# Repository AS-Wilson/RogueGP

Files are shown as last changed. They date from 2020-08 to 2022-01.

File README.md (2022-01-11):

# RogueGP
Rouge Racing Team GreenPower Repository, for all design documents (Mechanical, Electronic, and Software)

# Renders

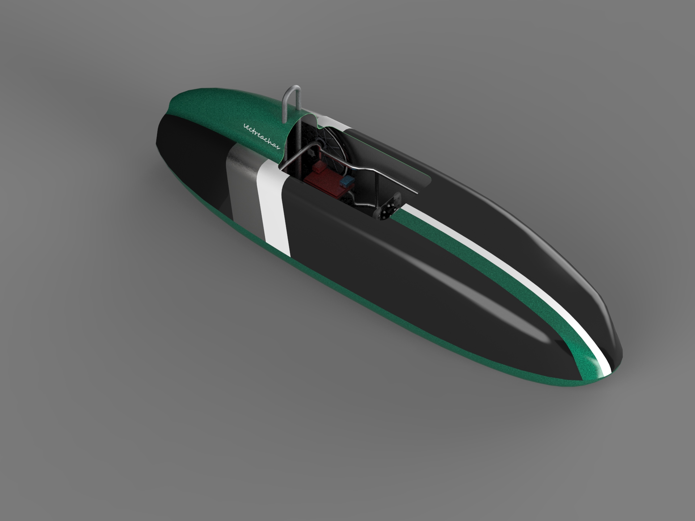
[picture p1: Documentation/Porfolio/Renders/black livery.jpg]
Black Livery


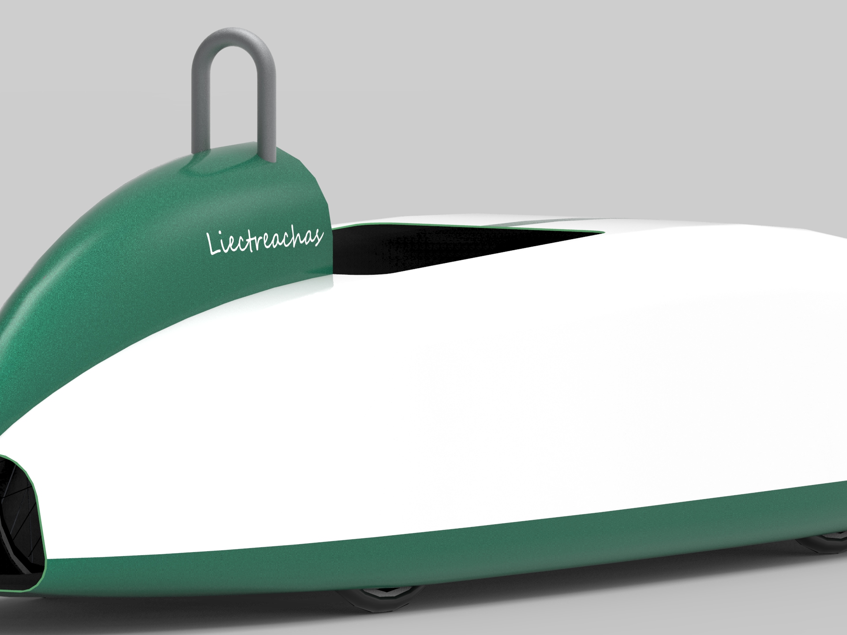
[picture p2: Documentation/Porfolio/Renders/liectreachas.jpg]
Liectreachas


# Current Build Progress and Some Race Photos

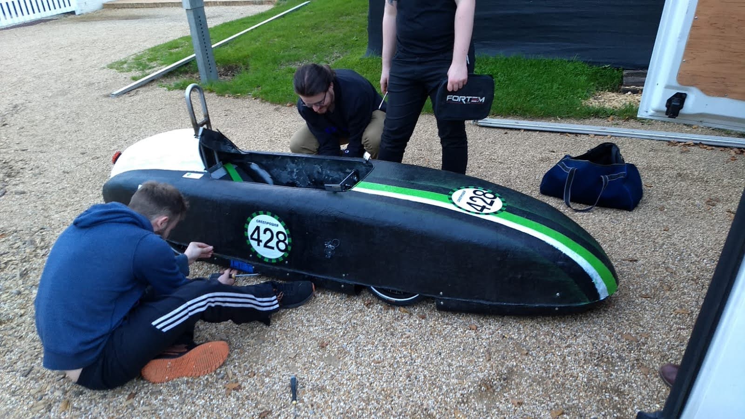
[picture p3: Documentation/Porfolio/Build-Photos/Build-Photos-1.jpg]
Build Photo One


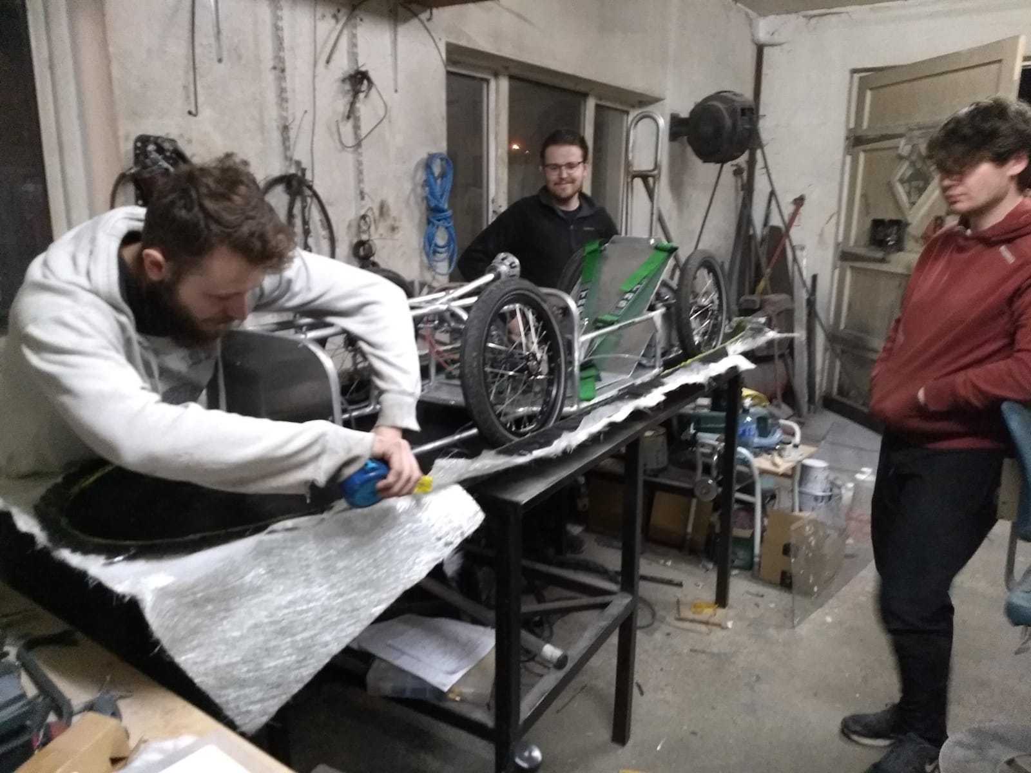
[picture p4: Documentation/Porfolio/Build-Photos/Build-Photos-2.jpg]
Build Photo Two


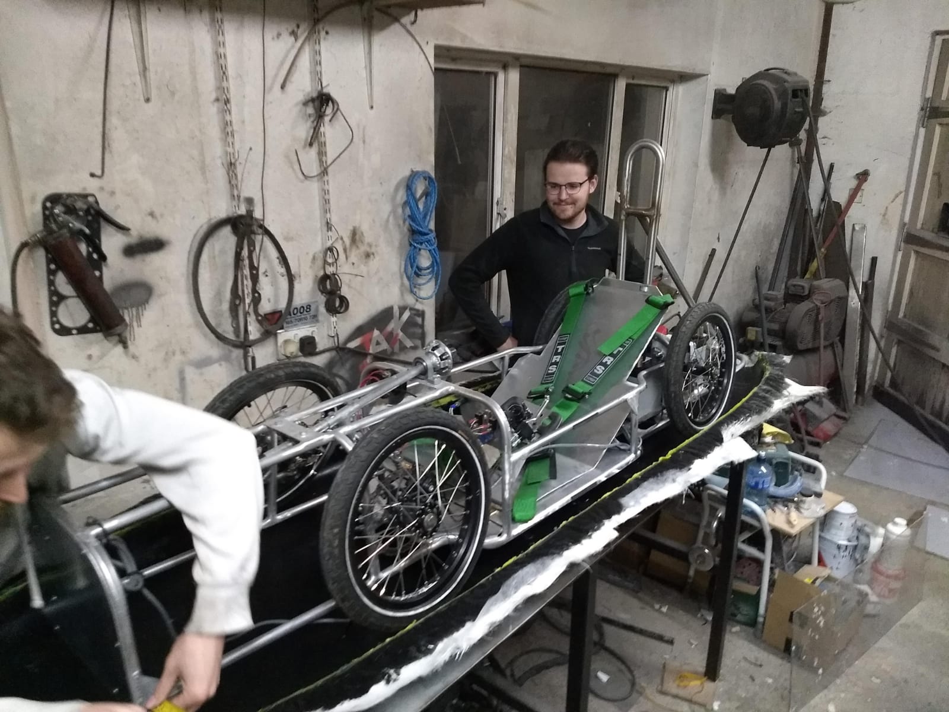
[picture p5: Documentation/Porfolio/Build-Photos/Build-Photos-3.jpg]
Build Photo Three


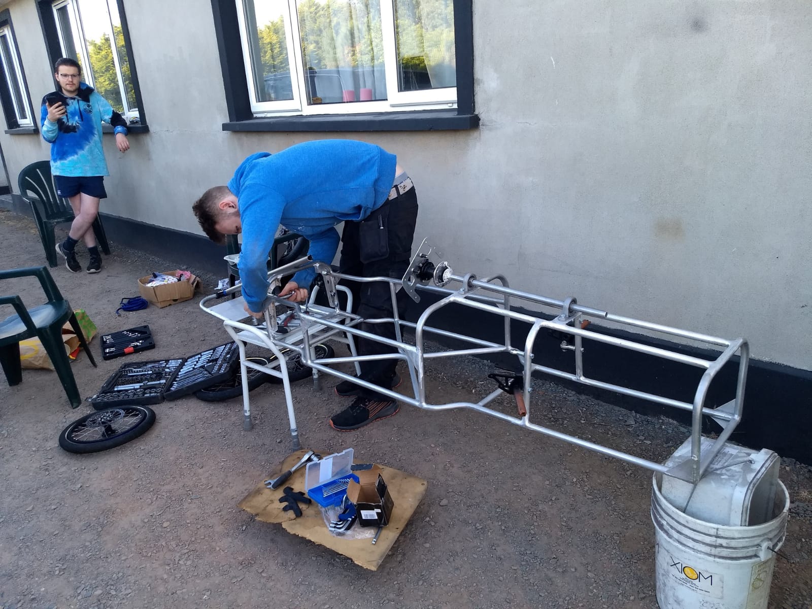
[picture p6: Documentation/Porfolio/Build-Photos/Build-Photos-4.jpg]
Build Photo Four


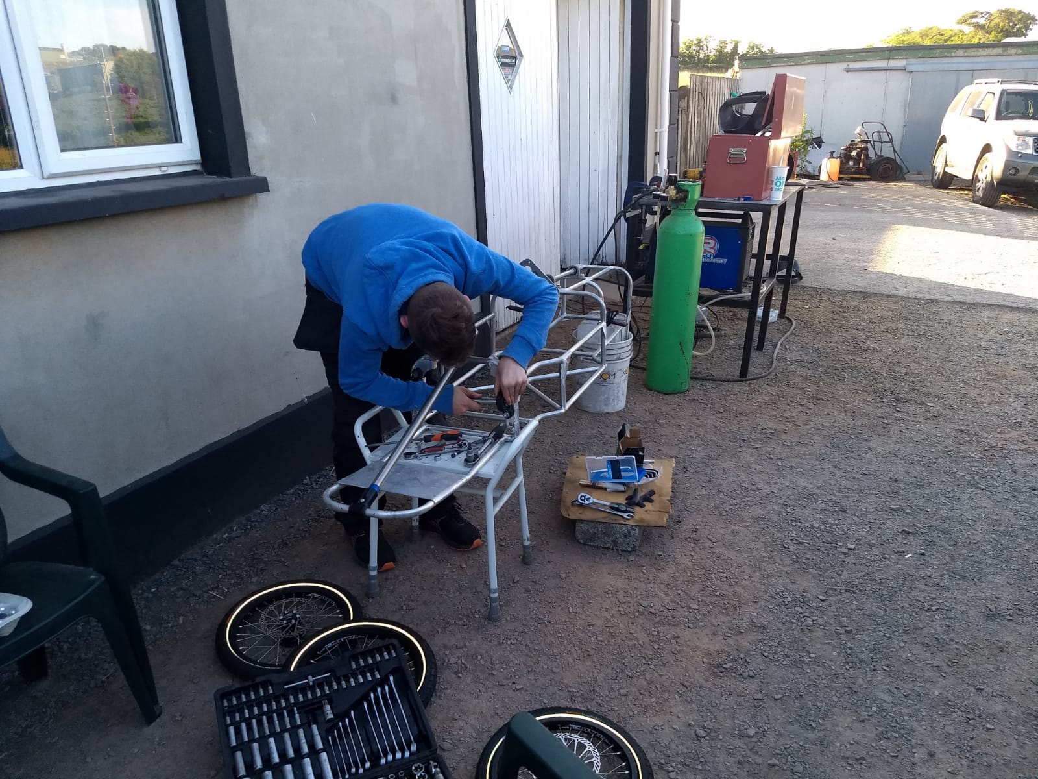
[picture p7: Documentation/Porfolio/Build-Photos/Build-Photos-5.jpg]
Build Photo Five


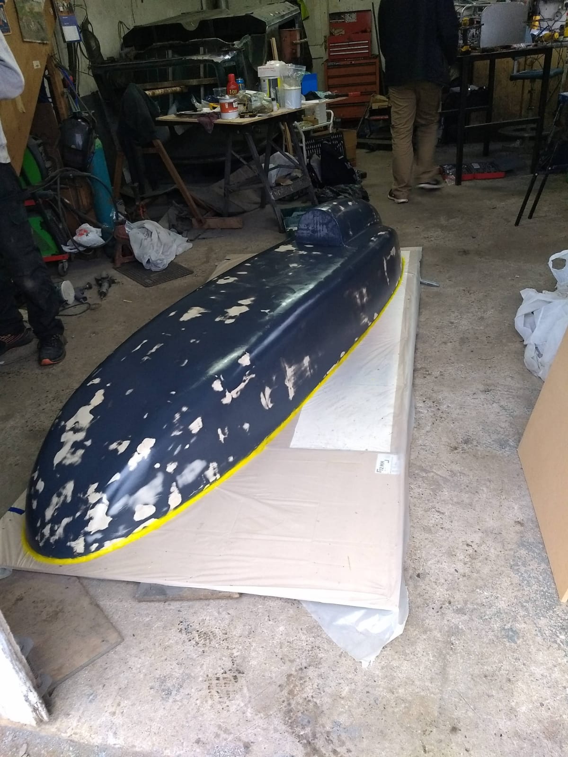
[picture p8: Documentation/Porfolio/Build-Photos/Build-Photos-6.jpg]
Build Photo Six


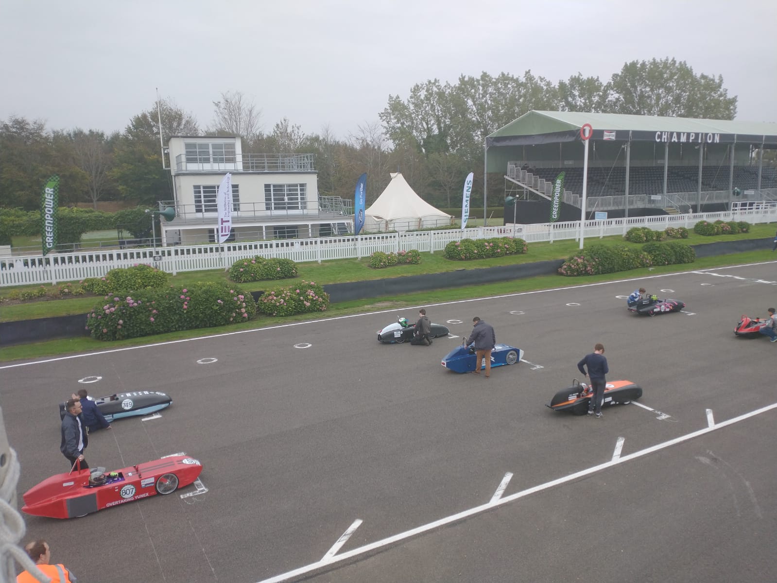
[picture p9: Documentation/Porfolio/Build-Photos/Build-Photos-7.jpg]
Build Photo Seven


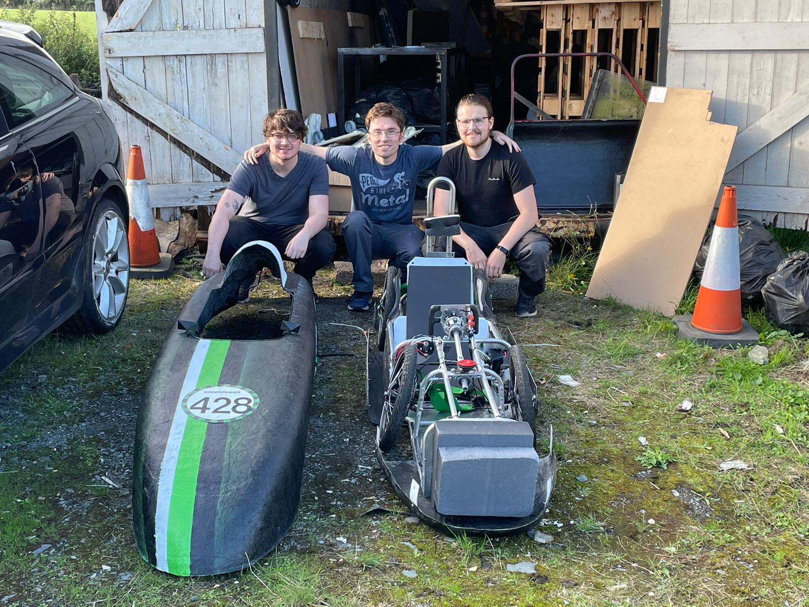
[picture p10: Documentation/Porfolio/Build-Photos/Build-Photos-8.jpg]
Build Photo Eight


Build Photo Nine

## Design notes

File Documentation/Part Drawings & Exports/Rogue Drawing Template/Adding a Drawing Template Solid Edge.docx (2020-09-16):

Adding a Drawing Template Solid Edge

Make a copy of the RR Drawing Template off Github.

Go to:

Program Files > Siemens > Solid Edge 2020 > Template > ISO Metric

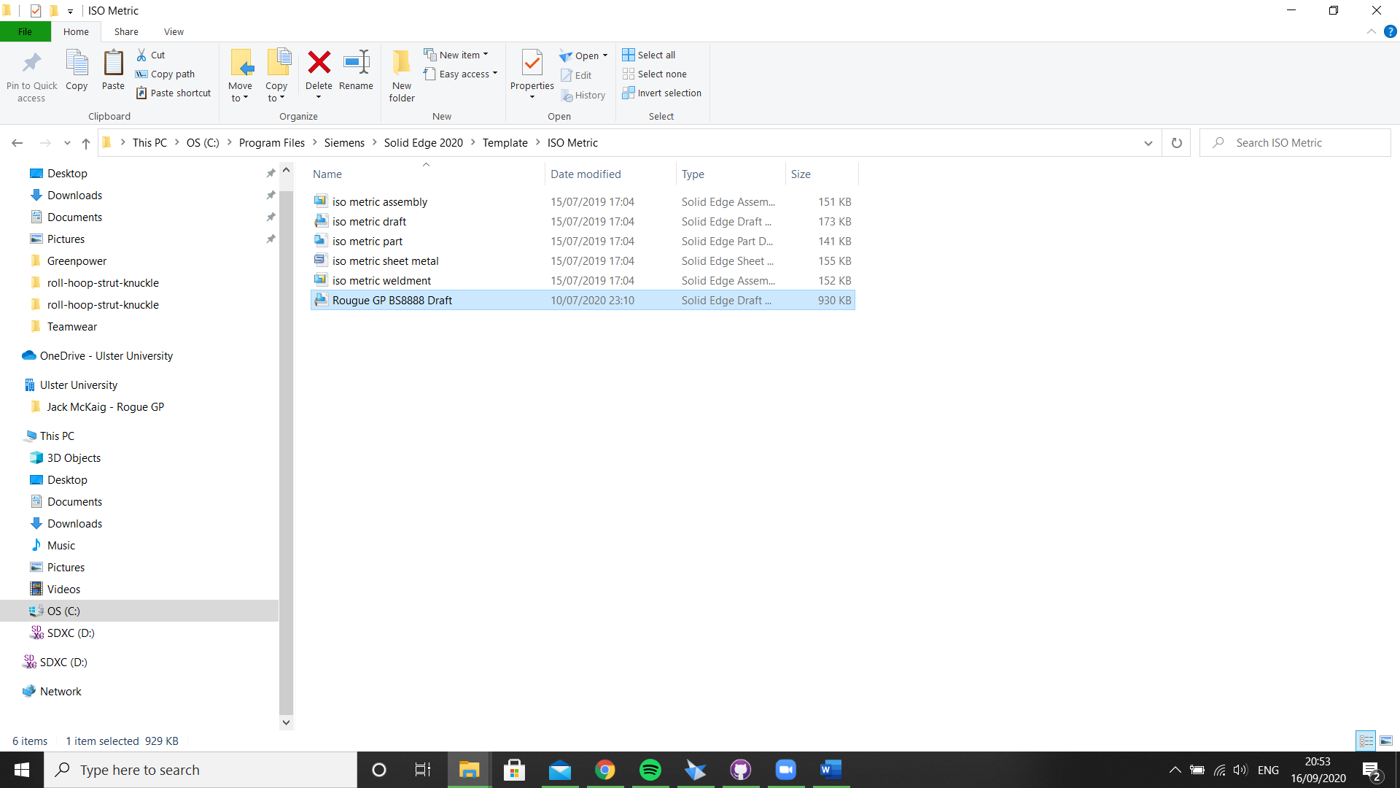
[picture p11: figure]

Paste Drawing template into this file and check Solid Edge to see if it has been added successfully.

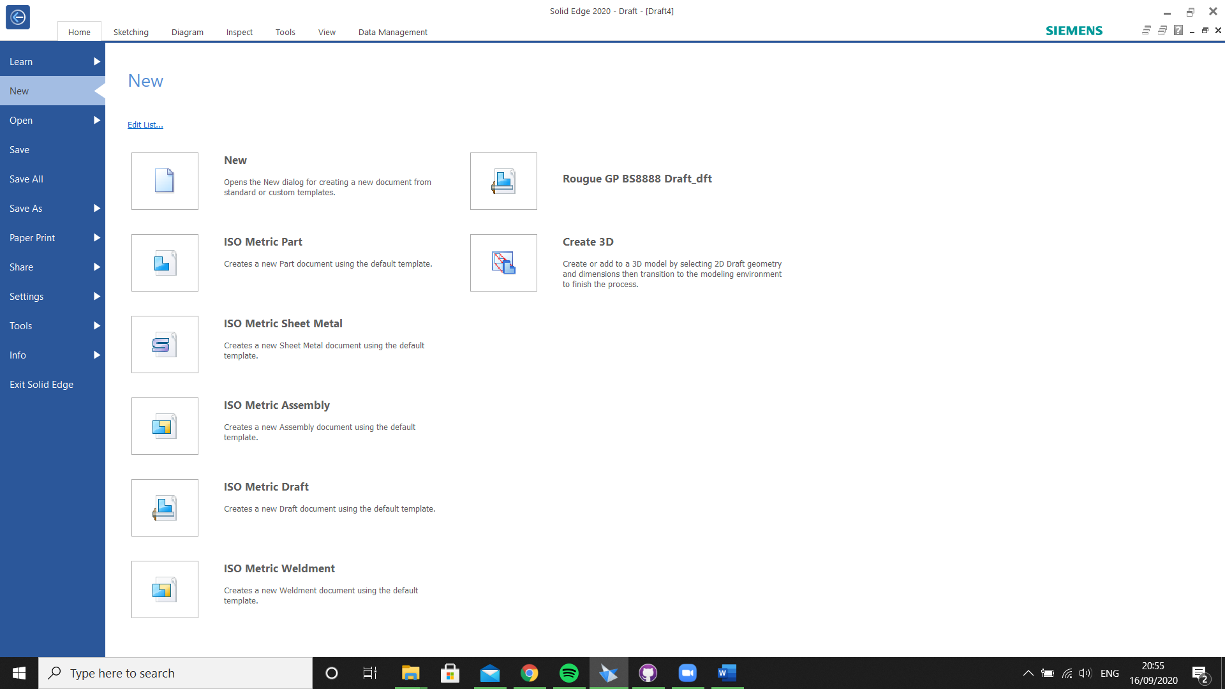
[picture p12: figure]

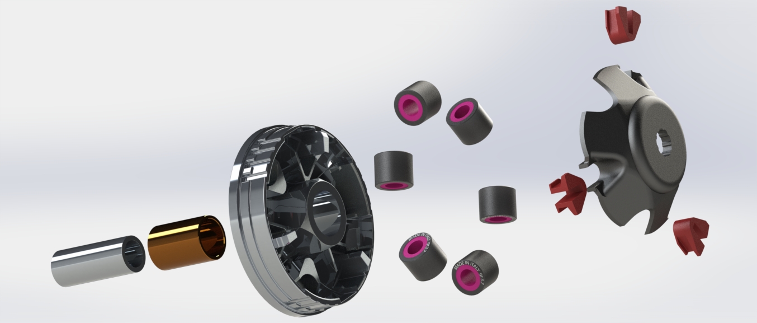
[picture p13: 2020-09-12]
Mechanical/drivetrain/CVT/example-CVT/Variator-multivar2000/rendering-exploded view.JPG

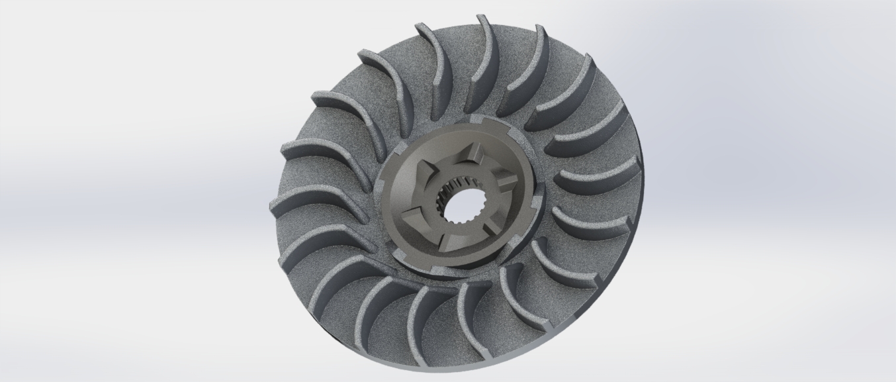
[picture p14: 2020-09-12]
Mechanical/drivetrain/CVT/example-CVT/ventilvar/rendering.JPG

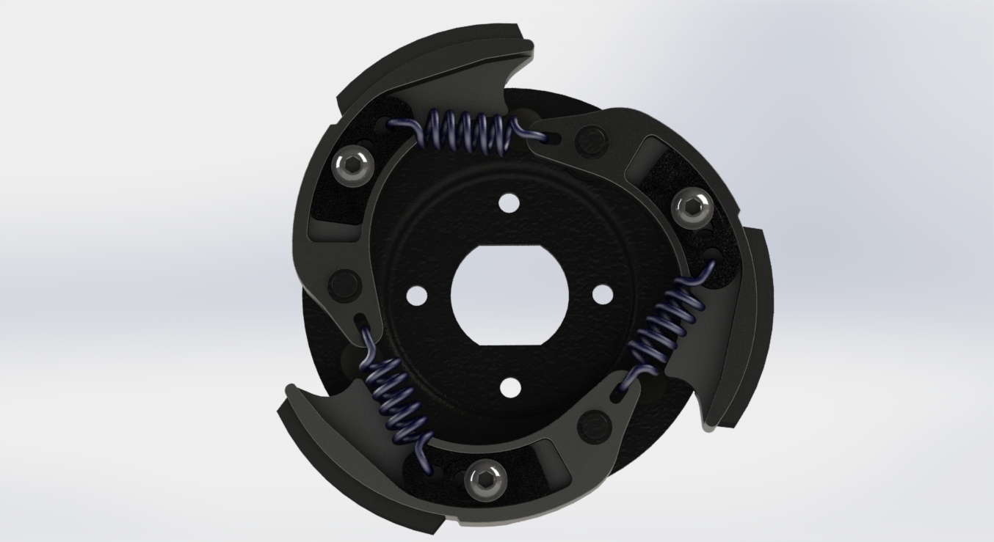
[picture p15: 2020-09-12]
Mechanical/drivetrain/CVT/example-CVT/Clutch/render4.JPG

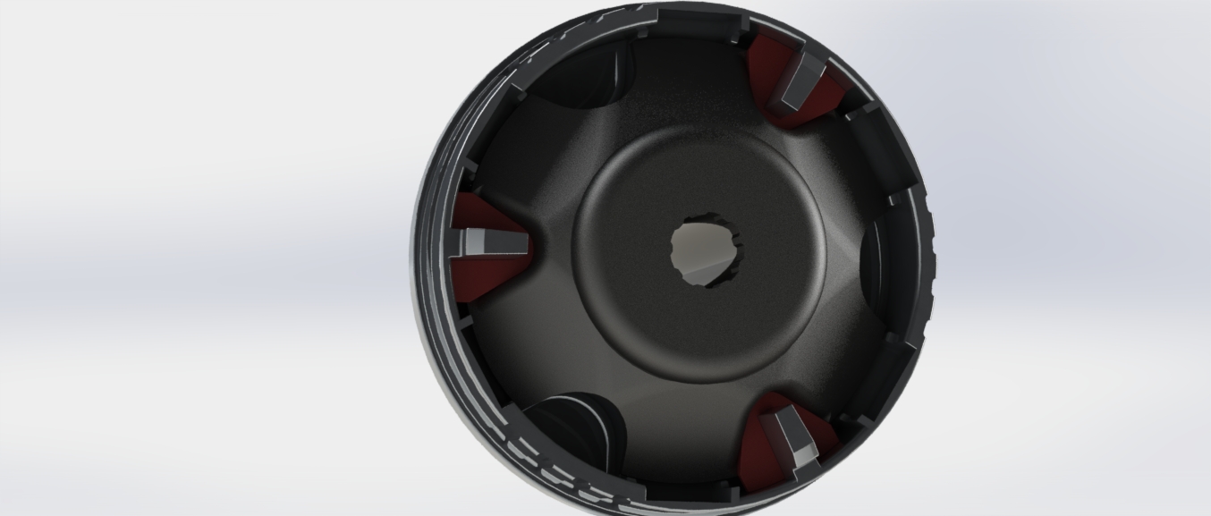
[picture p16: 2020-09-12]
Mechanical/drivetrain/CVT/example-CVT/Variator-multivar2000/preview.JPG

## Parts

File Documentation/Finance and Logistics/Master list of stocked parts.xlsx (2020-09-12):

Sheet: Steering
 | Steering system components |  |  | Procurment
Item No. | Component/materials list | Required Quantity | Stocked Quantity | Quote 1 | Quote 2 | Ordered?
1 | Threaded bar m8 2 metre | 1 | 5 | N/A | N/A | N/A
2 | Upright | 5 | 2 | £176 for pair (https://www.greenpower.co.uk/product/308) | N/A | Y
3 | steering column | 1 | 3 | £22.65 each (https://www.kkckartshop.co.uk/steering-column-m8-x-550mm.html) | £23 each (https://www.zipnorth.com/product/steering-column-m8/) | Y
4 | steering pillow bearings |  |  | £7.70 each (https://simplybearings.co.uk/shop/p22932/SBPP204-Pressed-Steel-Pillow-Block-Housing-with-20mm-Insert/product_info.html) | £10 each (http://www.bearingshopuk.co.uk/lpb20-pressed-steel-pillow-block/)
5 |  |  |  |  |  | made in house
6
7
8
9
10
11
12
13
14
15
16
17
18
19
20

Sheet: Power Unit
 | Power Unit components |  |  | Procurment
Item No. | Component/materials list | Quantity | Stocked? | Quote 1 | Quote 2 | Ordered?
1 | Spare Motor | 1 |  | £161.03 each (https://www.greenpower.co.uk/product/163) | N/A | Y
2 | Scooter for CVT and brakes | 2
3 | Thick aluminium bar for heatsink | 1
4 | Thermal paste | TBC
5 | Cooling fan | 2
6 | Motor | 1
7
8
9
10
11
12
13
14
15
16
17
18
19

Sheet: Wheels and Brakes
 | Wheels and brakes components |  |  | Procurment
Item No. | Component/materials list | Quantity | Stocked? | Quote 1 | Quote 2 | Ordered?
1 | 16" wheel rims | 4
2 | 16" rim tape | 4
3 | 16" tyres | 4
4 | 16" tyre tubes | 6
5 | Brake cable | 2
6 | brake lever | 2
7 | Cable caps |  |  | £1 for 10 (https://www.halfords.com/cycling/bike-parts/bike-brakes/halfords-gear-brake-cable-end-covers) | £1.49 for 10 (https://www.chainreactioncycles.com/lifeline-cable-ends/rp-prod155573?sku=sku568333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)
8 | Drum brake set | 1
9
10
11
12
13
14
15
16
17
18
19
20

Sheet: Chassis and Bodywork
 | Chassis frame components |  |  | Procurment
Item No. | Component/materials list | Quantity | Stocked? | Quote 1 | Quote 2 | Ordered?
1 | steel roll bar 3m 25mm 1.5mm | 1 |  | /
2 | rear axle bar 1m 3/4" | 1 |  | /
3 | box of pop rivets | 2
4 | bonnet pins | 8 |  | £17.99 for 2 (https://www.amazon.co.uk/CICMOD-Universal-Racing-Bonnet-without/dp/B07P1733YV?s=automotive) | 2 for £43.40 (https://www.aerocatch.com/product/120-2000-above-panel/)
5 | 20mm aluminium tubing 1.5mm | 20m |  | /
6 | Plywood Sheets 9mm | 3 |  | JP Corry qoute | £18.46 each (https://eglantinetimber.com/product/plywood/) | Y
7
8 | Flat bar 4m 20x3mm | 1 |  | /
9 | Flat bar 4m 20x2mm | 1 |  | /
10
11 | Blue foam sheet | 6 |  | £28.35 each minimum qty = 6 (https://www.panelsystems.co.uk/product/styrofoam) | £51.40 each (http://modelshop.co.uk/Shop/Item/Styrofoam-100mm-large-sheet/ITM7246) | Y
12
13
14
15
16
17
18
19
20

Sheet: Safety Equipment
 | Safty Equipment |  |  | Procurment
Item No. | Component/materials list | Quantity | Stocked? | Quote 1 | Quote 2 | Ordered?
1 | New Helmets | 2
2 | 5 point harness | 1 |  | £178.00 each (https://www.greenpower.co.uk/product/71) | £74.98 each (https://www.demon-tweeks.com/uk/race-safety-accessories-lightweight-nascar-5-point-harness-546549/)
3 | mirrors | 2
4
5
6
7
8
9
10
11
12
13
14
15
16
17
18
19
20

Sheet: Fasteners
 | Fasters |  |  | Procurment
Item No. | Component/materials list | Quantity | Stocked? | Quote 1 | Quote 2 | Ordered?
1
2
3
4
5
6
7
8
9
10
11
12
13
14
15
16
17
18
19
20

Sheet: Livery
 | Livery materials |  |  | Procurment
Item No. | Component/materials list | Quantity | Stocked? | Quote 1 | Quote 2 | Ordered?
1 | Vinyl sheet (purple)
2 | Vinyl USSE logo
3 | Vinyl Ulster University logo
4 | Vinyl Santaner logo (red)
5
6
7
8
9
10
11
12
13
14
15
16
17
18
19
20

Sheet: Wiring and Electronics
 | Wiring components |  |  | Procurment
Item No. | Component/materials list | Quantity | Stocked? | Quote 1 | Quote 2 | Ordered?
1 | New Batteries | 2 |  | £60.74 each (https://www.greenpower.co.uk/product/177) | N/A | Y
2 | 10m of 10mm red wire | 1 |  | £26.70 for 10m (https://uk.farnell.com/pro-power/pp001276/tri-rated-wire-10mm2-red-1m/dp/2528181?st=10mm%20red%20wire) | N/A | \
3 | 10m of 10mm black wire | 1 |  | £26.70 for 10m (https://uk.farnell.com/pro-power/pp001192/tri-rated-wire-10mm2-black-1m/dp/2528088) | N/A | \
4 | Reel of thin black wire | 1 |  | \ | \ | \
5 | Reel of thin red wire | 1 |  | £22.88 for 100m (https://uk.farnell.com/pro-power/pp001272/tri-rated-wire-1-5mm2-red-100m/dp/2501520?st=1.5mm%20red%20wire) | N/A | \
6 | box of Crimp terminals | 2 |  | \ | \ | \
7 | Brake light | 1 |  | £9.95 for 4 (https://www.amazon.co.uk/Justech-Position-Universal-Trailer-Caravan/dp/B078J17YDH) | 11.30 for 1 (https://www.trailertek.com/trailer-parts/lighting/led-lights/led-autolamps-81rmb-square-stop-tail-lamp-12v-24v) | \
8 | microswitch | 2 |  | £11.83 for 5 (https://uk.rs-online.com/web/p/microswitches/1594449/) | N/A | \
9 | Accelerator switch (Red Button) | 2 |  | £3.71 each (https://uk.farnell.com/multicomp/mcpas6b2m1ce3/switch-spst-0-4a-32vac-ip67-red/dp/1638334) | N/A | \
10 | horn | 1 |  | £10.82 each (https://www.arc-components.com/0-642-16-12v-420hz-high-tone-2-pole-electric-horn-2373.html) | £14.55 each (https://www.greenpower.co.uk/product/39) | \
11 | horn switch (Blue Button) | 2 |  | £2.74 each (https://uk.farnell.com/multicomp/mcpas6b2m1ce7/switch-push-button-spst-ip67-blue/dp/1638332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) | N/A | \
12 | relay | 2 |  | £7.67 each (https://uk.farnell.com/te-connectivity/v23134j53d642/relay-automotive-spst-no-24vdc/dp/9913777) | N/A | \
13 | fuse | 10 |  | £7.83 for 10 (https://uk.rs-online.com/web/p/car-fuses/2193592/) | N/A | \
14 | Isolator Key and switcth | 1 |  | \ | \ | \
15 | bag of short cable ties | 1 |  | \ | \ | \
16 | bag of long cable ties | 1 |  | \ | \ | \
17 | bag of self ahesive pads | 1 |  | \ | \ | \
18 | New battery connectors | 2 |  | £14.85 for 2 (https://www.greenpower.co.uk/product/168) | £7.39 for 2 (https://www.amazon.co.uk/Qiorange-Release-Terminals-Motorhome-Terminal/dp/B075JCNMDC) | Y
19 | spare battery terminals | 4 |  | £9.60 for 2 (https://www.greenpower.co.uk/product/297) | N/A | Y
20 | fuse holder | 1 |  | £9.02 each (https://uk.rs-online.com/web/p/inline-fuse-holders/2506285/) | N/A | \
21
22
23 |  | 4
24 |  | 4
25 |  | 4
26 |  | 4

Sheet: Race Weekend items
 | Race weekend items |  |  | Procurment
Item No. | Component/materials list | Quantity | Stocked? | Quote 1 | Quote 2 | Ordered?
1
2 | New Overalls with gloves | 4 to 6
3 | Team shirts | 6 |  |  |  | Y
4 | car stand | 1
5 | GoPro | 1
6 | Roll of masking tape | 2
7 | pit board | 2
8 | umbrella for wet race start | 2
9 | Gazebo | 1
10 | Roll of Duct Tape | 2
11 | Foot/plug in pump | 1
12 | Battery insulation boxes | 2
13
14
15
16
17
18
19
20

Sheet: Communication
 | Communication items |  |  | Procurment
Item No. | Component/materials list | Quantity | Stocked? | Quote 1 | Quote 2 | Ordered?
1 | Team radios | 4
2 | closed face helmet mic | 2
3 | Telemetry system | 1 |  | \ | \ | outsourced
4
5
6
7
8
9
10
11
12
13
14
15
16
17
18
19
20

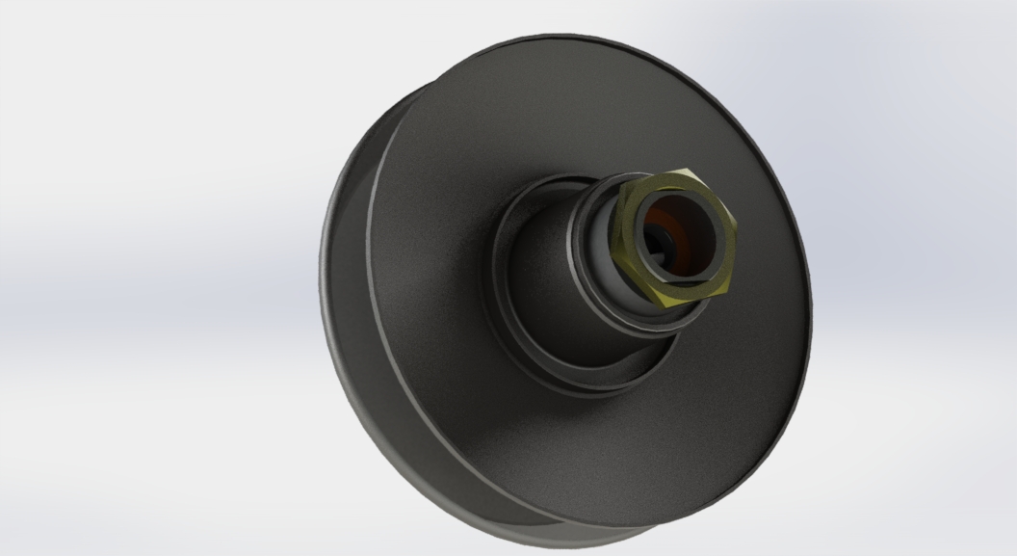
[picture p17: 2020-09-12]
Mechanical/standard-parts-&-example-designs/example-CVT/Torque-Driver/preview.JPG

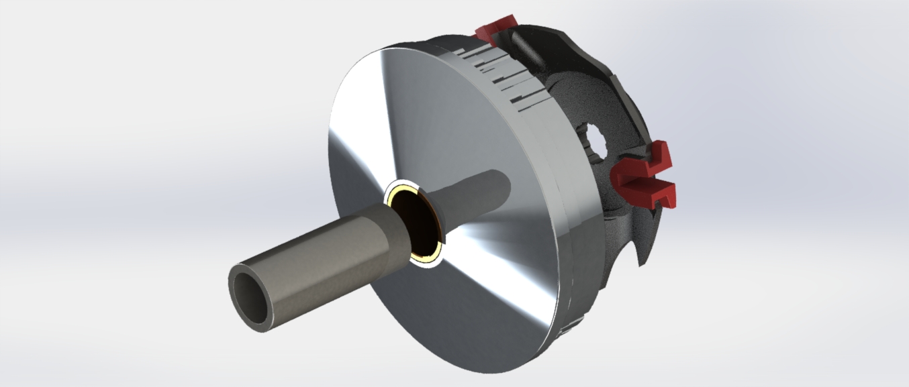
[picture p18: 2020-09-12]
Mechanical/standard-parts-&-example-designs/example-CVT/Variator-multivar2000/preview2.JPG

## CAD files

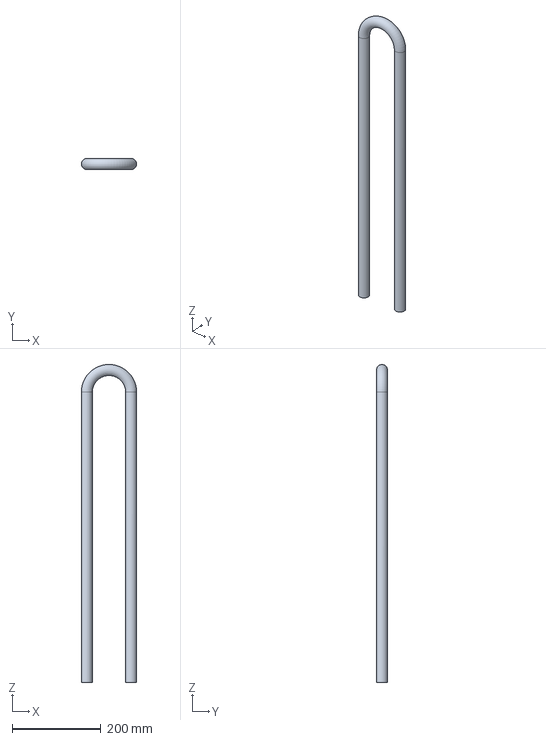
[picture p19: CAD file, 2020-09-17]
Mechanical/MB1000-chassis/roll-hoop/R720x100-roll-hoop/Exports/R720x100-roll-hoop-for-assembly.stp
125.0 x 25.0 x 717.4 mm

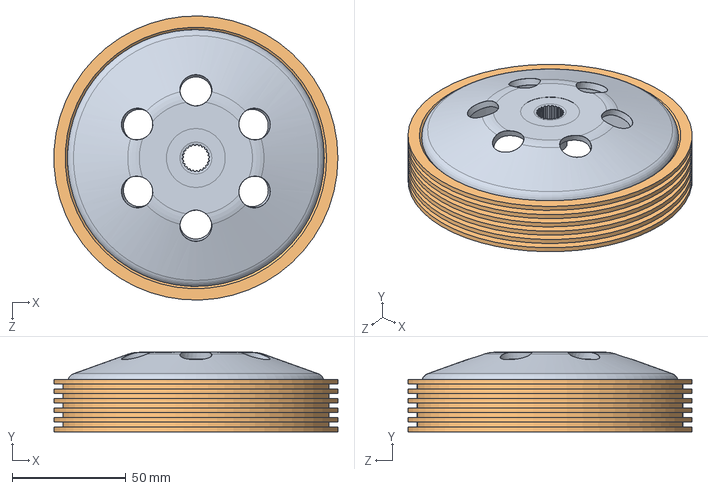
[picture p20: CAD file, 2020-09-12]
Mechanical/standard-parts-&-example-designs/example-CVT/Clutch-Bell/CLBAssembly.SLDASM
124.9 x 35.0 x 124.9 mm
CLBPart1
CLBPart2

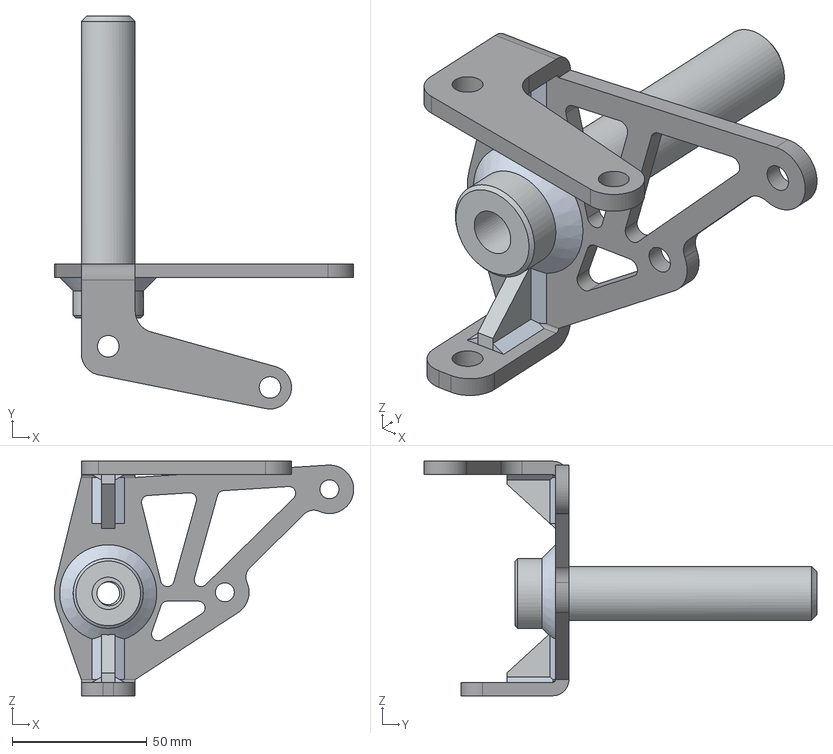
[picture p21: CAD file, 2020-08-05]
Mechanical/Suspension-&-Steering/Uprights/RH-Upright/Exports/RH-Upright-Assembly.stp
111.0 x 145.8 x 87.0 mm
RH-upright
RH-Upright-Assembly_469_690_Fillet 7_oa_0
RH-Upright-Assembly_469_690_Fillet 7_oa_1
front-axle
RH-Upright-Assembly_469_690_Fillet 7_oa_2
RH-Upright-Assembly_469_690_Fillet 7_oa_3
upright-gusset x 2
RH-Upright-Assembly_469_690_Fillet 7_oa_4
RH-Upright-Assembly_469_690_Fillet 7_oa_5
RH-Upright-Assembly_469_690_Fillet 7_oa_6

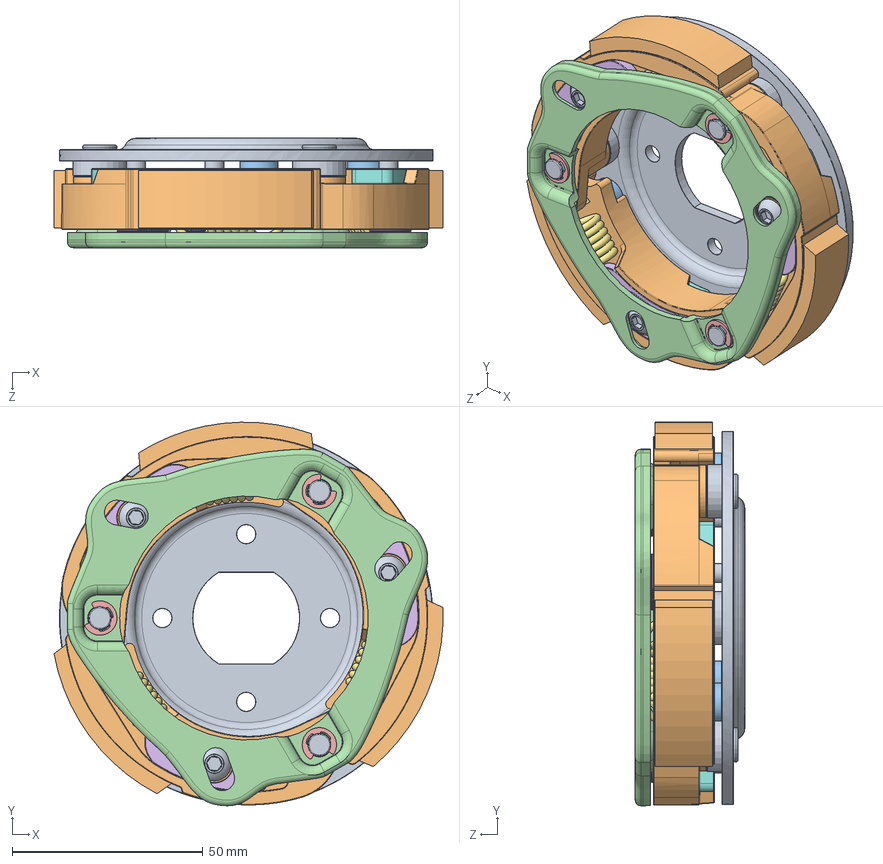
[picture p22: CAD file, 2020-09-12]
Mechanical/drivetrain/CVT/example-CVT/Clutch/CLAssembly.SLDASM
102.1 x 100.7 x 28.8 mm
frix1
coupling jaws x 3
CLpart7 x 3
CLPart3
seeger x 3
CLPart5 x 3
spring x 3
CLPart6 x 3
CLPart2 x 3
CLpart8 x 3

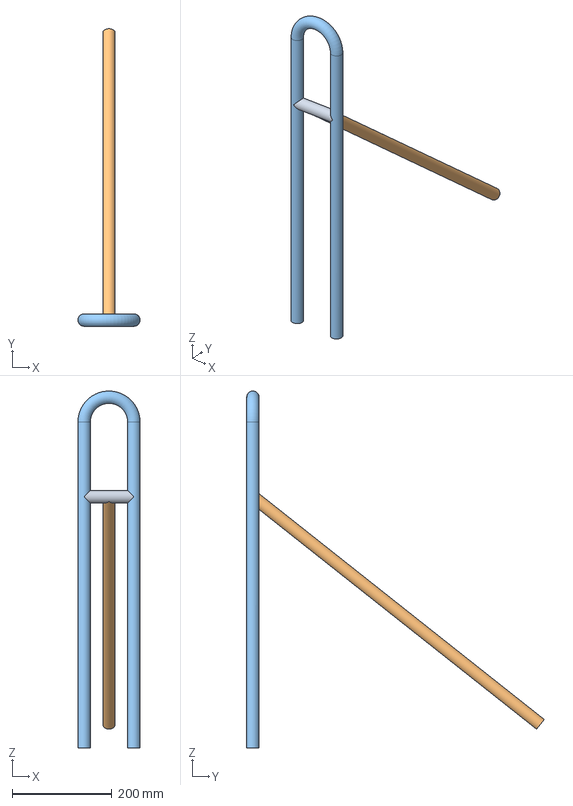
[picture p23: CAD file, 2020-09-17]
Mechanical/MB1000-chassis/roll-hoop/R720x100-roll-hoop/Exports/R720x100-roll-hoop-assembly.stp
125.0 x 598.1 x 717.5 mm
R720x100-roll-hoop-cross-member
R720-roll-hoop-bracing-strut
R720x100-roll-hoop-for-assembly

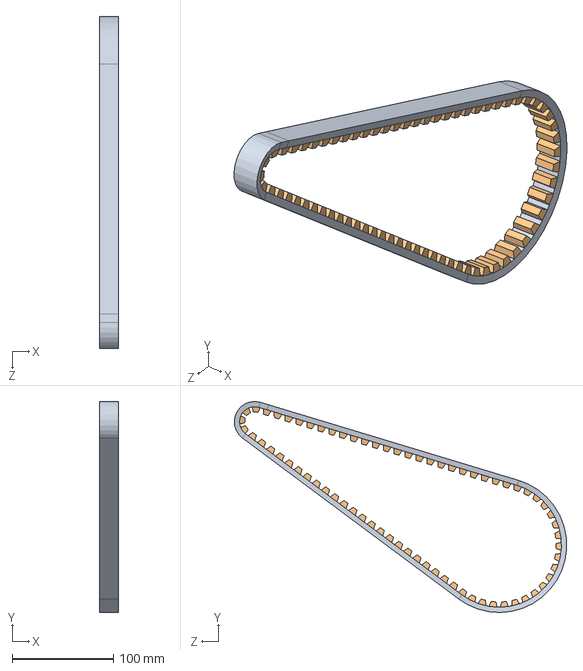
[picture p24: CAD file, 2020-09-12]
Mechanical/standard-parts-&-example-designs/example-CVT/cinghia/Assieme12.SLDASM
19.0 x 208.0 x 327.5 mm
extbelt
dente x 70

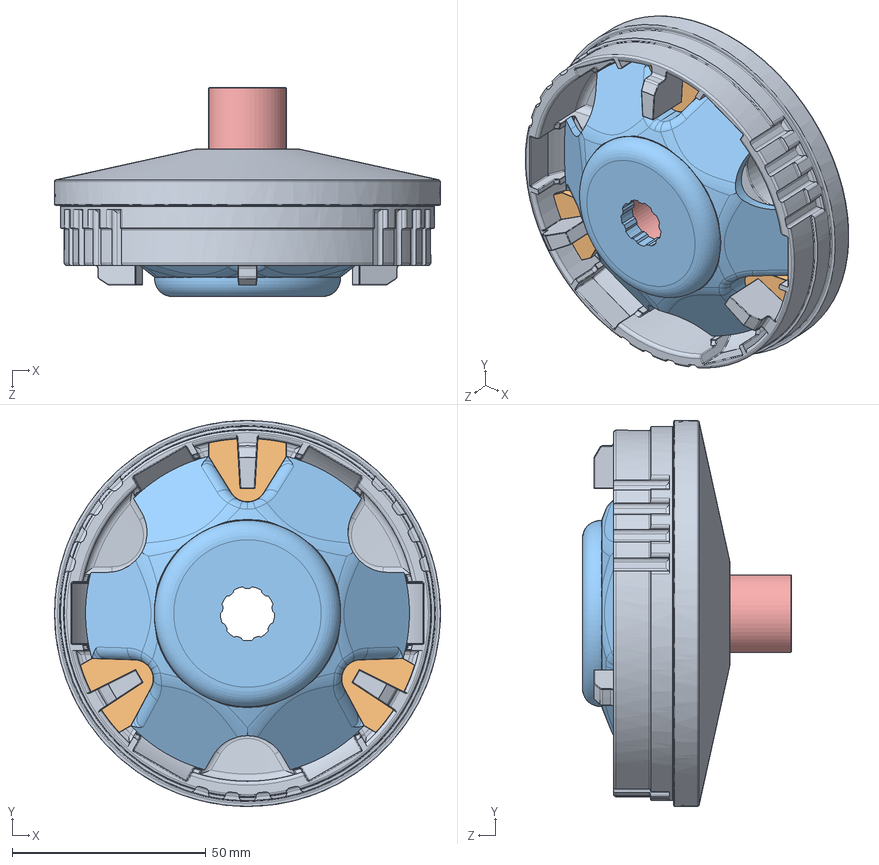
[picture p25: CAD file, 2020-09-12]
Mechanical/drivetrain/CVT/example-CVT/Variator-multivar2000/Assembly.SLDASM
99.5 x 99.5 x 54.0 mm
moved half-pulley
slider x 3
fixed cover
bushing
hub
roller weight x 6

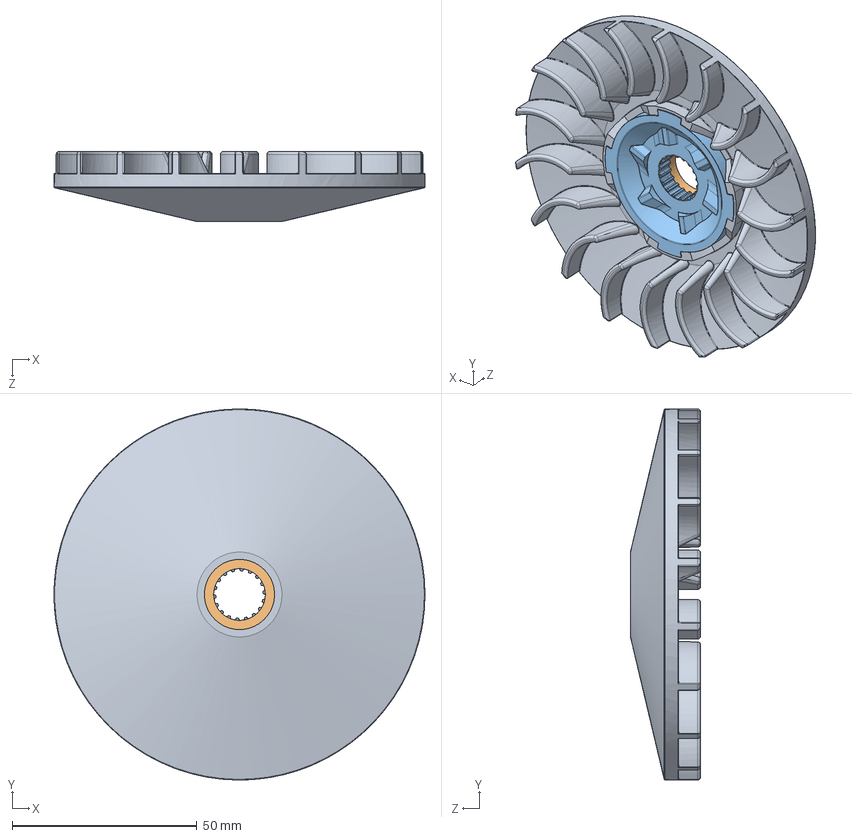
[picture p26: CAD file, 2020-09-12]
Mechanical/drivetrain/CVT/example-CVT/ventilvar/puleggia fissa.SLDASM
100.5 x 100.5 x 19.0 mm
ventilvar
VENParte4
VENParte5

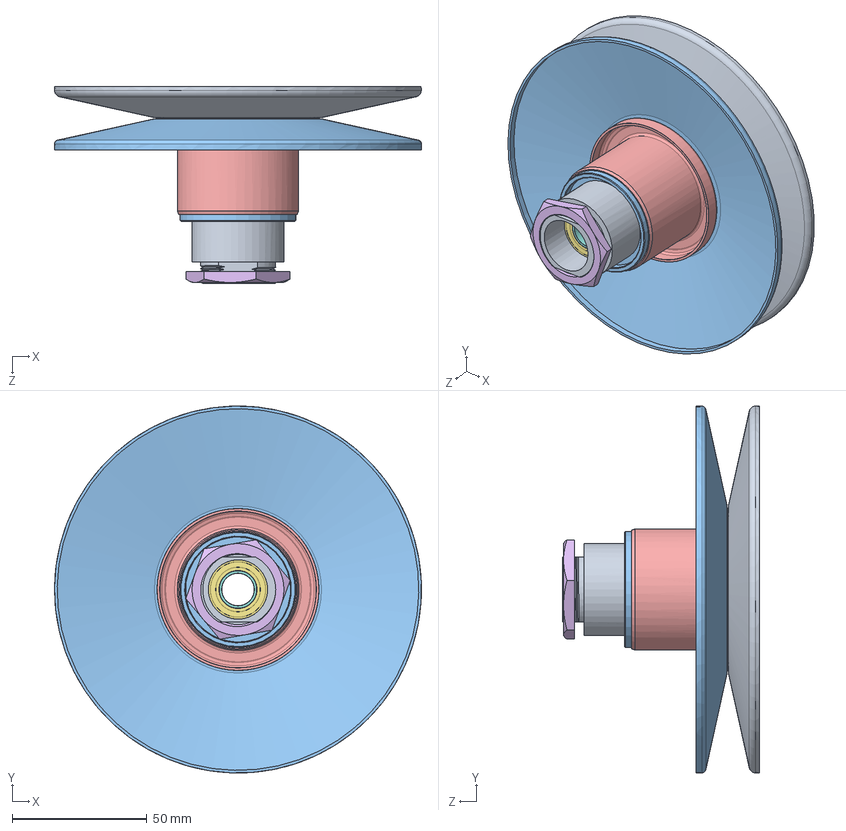
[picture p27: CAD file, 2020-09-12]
Mechanical/standard-parts-&-example-designs/example-CVT/Torque-Driver/TQAssieme1.SLDASM
136.0 x 136.0 x 73.0 mm
TQParte4
Parte1GR
Parte2GR x 2
Parte3GR
Parte4GR x 13
TQParte5
Parte3SM
Parte2SM
Parte1SM
Parte6 x 3
TQParte2
guarnizione x 2
TQParte1
TQParte7

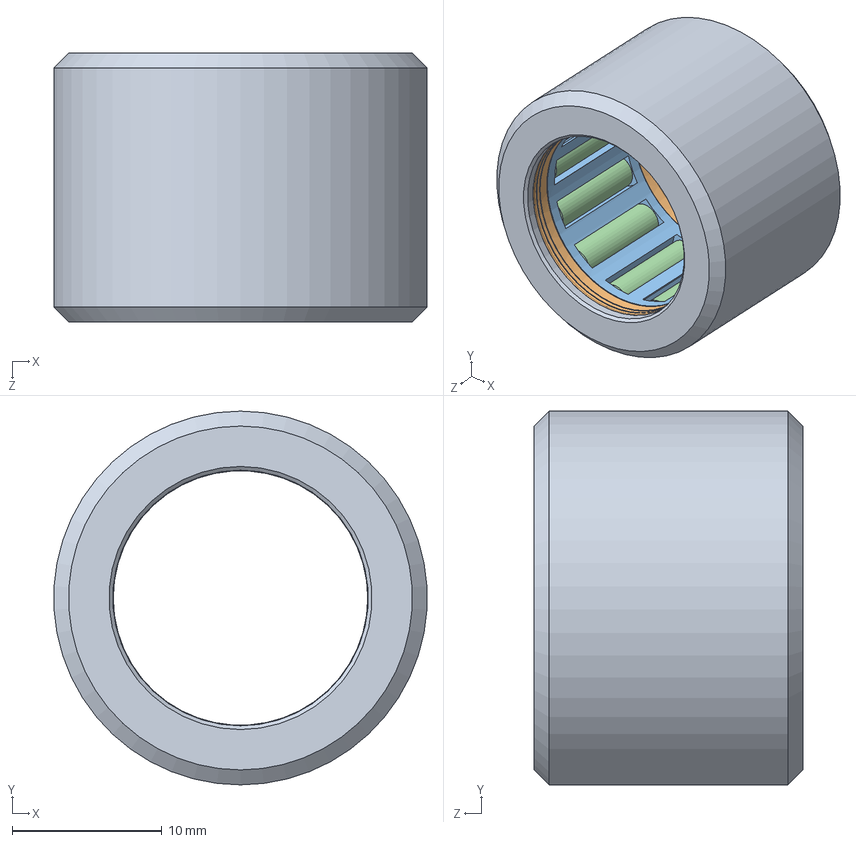
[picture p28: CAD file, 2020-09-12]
Mechanical/drivetrain/CVT/example-CVT/Torque-Driver/GR.SLDASM
25.0 x 25.0 x 18.0 mm
Parte1GR
Parte2GR x 2
Parte3GR
Parte4GR x 13

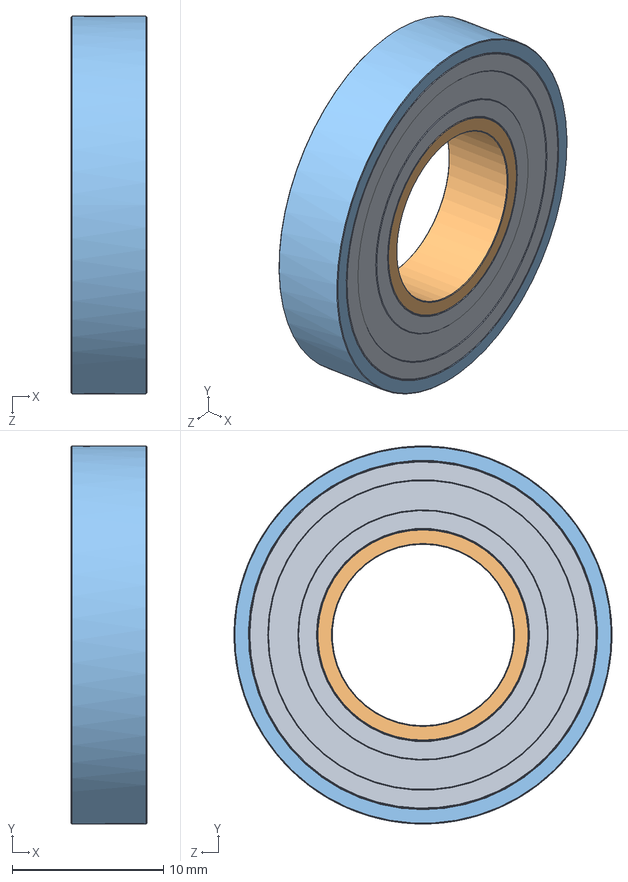
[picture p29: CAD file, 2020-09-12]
Mechanical/standard-parts-&-example-designs/example-CVT/Torque-Driver/TQAssieme3.SLDASM
5.00 x 25.0 x 25.0 mm
Parte3SM
Parte2SM
Parte1SM

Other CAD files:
Documentation/Part Drawings & Exports/Exports/2020-heat-sink.stp
Documentation/Part Drawings & Exports/Exports/LH-axle.stp
Documentation/Part Drawings & Exports/Exports/RH-axle.stp
Documentation/Part Drawings & Exports/Exports/roll-hoop-strut-knuckle-plain-coupler.stp
Documentation/Part Drawings & Exports/Exports/roll-hoop-strut-knuckle.stp
Documentation/Part Drawings & Exports/Exports/roll-hoop-u-bolt-saddle.stp
Mechanical/MB1000-Chassis/battery-holder/battery-tray-flat.dxf
Mechanical/MB1000-Chassis/battery-holder/battery-tray.psm
Mechanical/MB1000-Chassis/battery-holder/mount-corner.psm
Mechanical/MB1000-Chassis/battery-holder/mount-side.psm
Mechanical/MB1000-Chassis/battery-holder/mount-top.psm
Mechanical/MB1000-Chassis/front-steering-mount-plate.psm
Mechanical/MB1000-Chassis/gusset.psm
Mechanical/MB1000-Chassis/rear-axle-mounts/manufacture/rear-axle mount-flat.psm
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

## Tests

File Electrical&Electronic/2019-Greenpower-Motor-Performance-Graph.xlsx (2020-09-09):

Torque Constant |  | 0.0995Nm/A
Starting Torque |  | 0.198Nm
Stall Current |  | 112A
Winding Resistance |  | 0.214Ohms
Current | RPM | Power In (W) | Torque Nm | Power Out (W) | Efficiency % | Heat Out (W)
5 | 2331 | 120 | 0.30 | 73.0 | 60.8 | 47.0
6 | 2307 | 144 | 0.40 | 96.3 | 66.9 | 47.7
7 | 2291 | 168 | 0.50 | 119.5 | 71.2 | 48.5
8 | 2265 | 192 | 0.60 | 141.8 | 73.9 | 50.2
9 | 2237 | 216 | 0.70 | 163.4 | 75.6 | 52.6
10 | 2209.51 | 240 | 0.80 | 184.4 | 76.8 | 55.6
11 | 2187.861 | 264 | 0.90 | 205.4 | 77.8 | 58.6
12 | 2166.212 | 288 | 1.00 | 226.0 | 78.5 | 62.0
13 | 2144.563 | 312 | 1.10 | 246.1 | 78.9 | 65.9
14 | 2122.914 | 336 | 1.20 | 265.8 | 79.1 | 70.2
15 | 2101.265 | 360 | 1.29 | 285.0 | 79.2 | 75.0
16 | 2079.616 | 384 | 1.39 | 303.8 | 79.1 | 80.2
17 | 2057.967 | 408 | 1.49 | 322.1 | 78.9 | 85.9
18 | 2036.318 | 432 | 1.59 | 339.9 | 78.7 | 92.1
19 | 2014.669 | 456 | 1.69 | 357.3 | 78.4 | 98.7
20 | 1993.02 | 480 | 1.79 | 374.3 | 78.0 | 105.7
21 | 1971.371 | 504 | 1.89 | 390.8 | 77.5 | 113.2
22 | 1949.722 | 528 | 1.99 | 406.8 | 77.0 | 121.2
23 | 1928.073 | 552 | 2.09 | 422.4 | 76.5 | 129.6
24 | 1906.424 | 576 | 2.19 | 437.5 | 76.0 | 138.5
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

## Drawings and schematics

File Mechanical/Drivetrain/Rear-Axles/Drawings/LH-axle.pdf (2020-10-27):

1 | 2 | 3 | 4 | 5 | 6

A

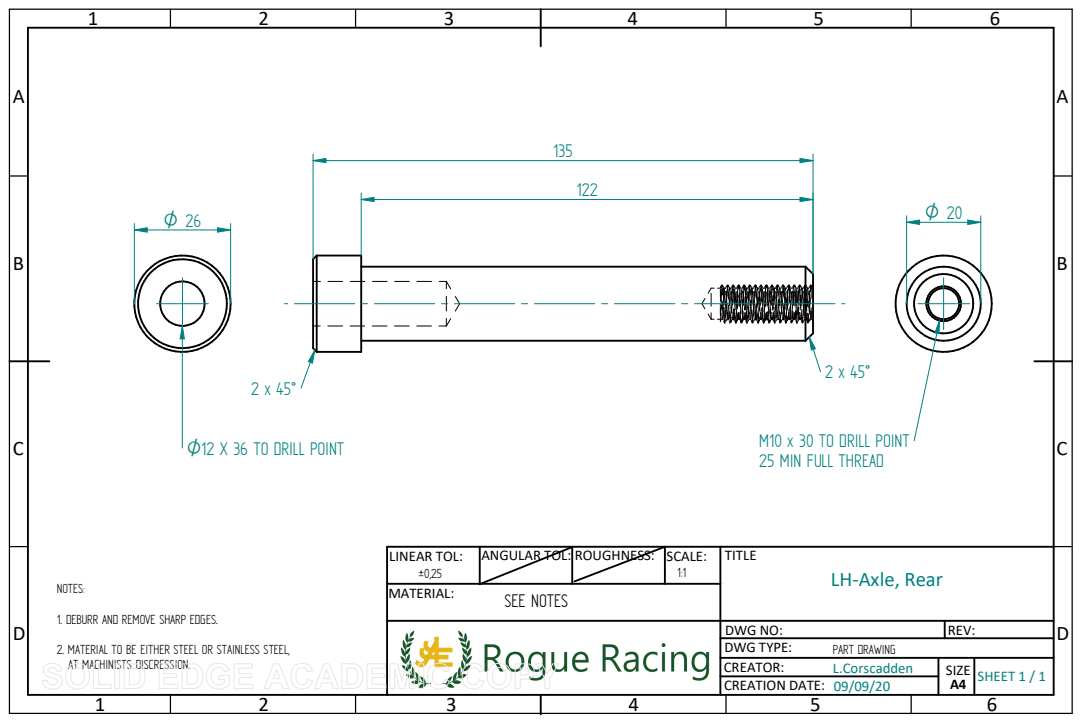
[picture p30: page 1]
SHEET 1 / 1 L.Corscadden 09/09/20; TITLE; DWG NO:; REV:; SIZE A4; LINEAR TOL:; ANGULAR TOL: ROUGHNESS:; MATERIAL:; SCALE:; DWG TYPE: CREATOR: CREATION DATE:; SEE NOTES; NOTES:; PART DRAWING

M10 x 30 TO DRILL POINT
25 MIN FULL THREAD

O12 X 36 TO DRILL POINT

LH-Axle, Rear

1. DEBURR AND REMOVE SHARP EDGES.
2. MATERIAL TO BE EITHER STEEL OR STAINLESS STEEL,
AT MACHINISTS DISCRESSION.

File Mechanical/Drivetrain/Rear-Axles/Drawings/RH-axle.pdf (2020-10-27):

1 | 2 | 3 | 4 | 5 | 6 | 7 | 8

B

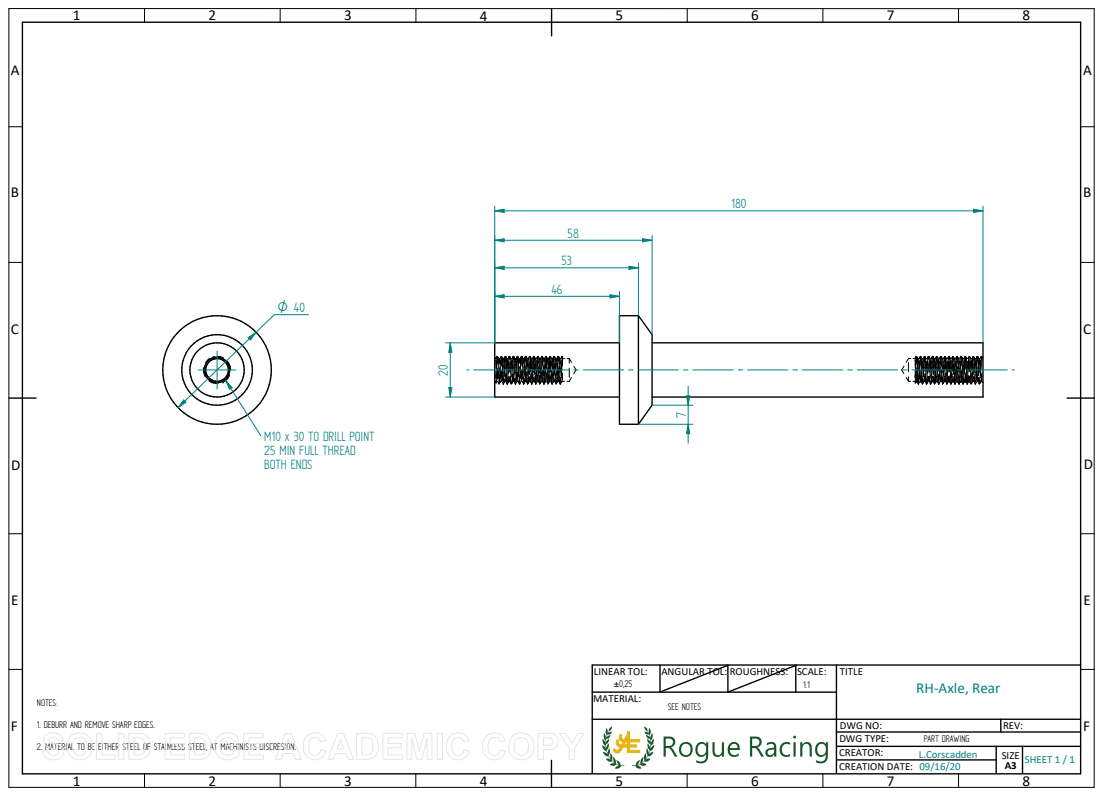
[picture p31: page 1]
SHEET 1 / 1 L.Corscadden 09/16/20; TITLE; DWG NO:; REV:; SIZE A3; LINEAR TOL:; ANGULAR TOL: ROUGHNESS:; MATERIAL:; SCALE:; DWG TYPE: CREATOR: CREATION DATE:; PART DRAWING; NOTES:; SEE NOTES

M10 x 30 TO DRILL POINT
25 MIN FULL THREAD
BOTH ENDS

RH-Axle, Rear

1. DEBURR AND REMOVE SHARP EDGES.

2. MATERIAL TO BE EITHER STEEL OF STAINLESS STEEL, AT MACHINISTS DISCRESION.

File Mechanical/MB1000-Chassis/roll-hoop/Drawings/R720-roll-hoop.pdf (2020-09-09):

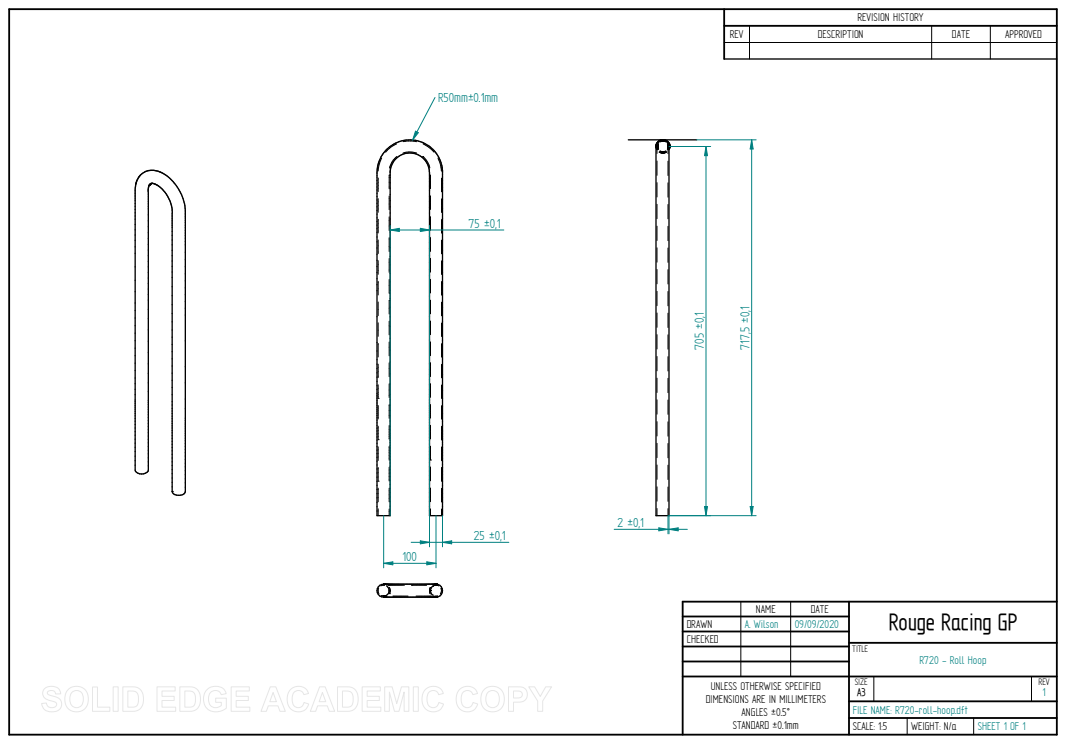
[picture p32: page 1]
TITLE; R720 - Roll Hoop; REV 1; SCALE: 1:5; WEIGHT: N/a; SHEET 1 OF 1; R50mmu0.1mm

REVISION HISTORY

REV | DESCRIPTION | DATE | APPROVED

NAME | DATE | Rouge Racing GP

DRAWN | A. Wilson | 09/09/2020
CHECKED

UNLESS OTHERWISE SPECIFIED
DIMENSIONS ARE IN MILLIMETERS
ANGLES ±0.5°
STANDARD ±0.1mm

SIZE
FILE NAME: R720-roll-hoop.dft

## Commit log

2020-08-05 AW - Initial Commit
    AW - Initial content commit from original OneDrive
    [LH-Upright-Assembly.cfg, LH-upright-flat.psm, LH-upright.psm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]
2020-09-09 Major updates to suspension and chassis
    [2019-Greenpower-Motor-Performance-Graph.xlsx, MB1000.cfg, R720-roll-hoop.cfg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]
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2020-09-11 Create battery clamp connecter.sldprt
    [battery clamp connecter.sldprt]
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2020-09-11 Create Battery with terminals.cfg
    [Battery with terminals.cfg]
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2020-09-11 Create Battery with terminals.sldasm
    [Battery with terminals.sldasm]
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2020-09-11 Create Body Assembly 2.cfg
    [Body Assembly 2.cfg]
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2020-09-11 Create Body Assembly 2.sldasm
    [Body Assembly 2.sldasm]
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2020-09-11 Create front left wheel.cfg
    [front left wheel.cfg]
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2020-09-11 Create GREEN CAR MOTOR MOUNT.psm
    [GREEN CAR MOTOR MOUNT.psm]
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2020-09-11 Create GREEN CAR MOTOR MOUNT.sldprt
    [GREEN CAR MOTOR MOUNT.sldprt]
2020-09-11 Create GREEN CAR SIDE PLATE.psm
    [GREEN CAR SIDE PLATE.psm]
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2020-09-11 Create GREEN CAR SIDE PLATE.sldprt
    [GREEN CAR SIDE PLATE.sldprt]
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2020-09-11 Create Lower Horizontal Tube.sldprt
    [Lower Horizontal Tube.sldprt]
2020-09-11 Create Lower Horizontal Tube_1.sldprt
    [Lower Horizontal Tube_1.sldprt]
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2020-09-11 Create Lower Side Tube.sldprt
    [Lower Side Tube.sldprt]
2020-09-11 Create Lower Side Tube_1.sldprt
    [Lower Side Tube_1.sldprt]
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2020-09-11 Create motor mound connecter part2.sldprt
    [motor mound connecter part2.sldprt]
2020-09-11 Create motor mound connecter part2_1.sldprt
    [motor mound connecter part2_1.sldprt]
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2020-09-11 Create motor mound connecter.sldprt
    [motor mound connecter.sldprt]
2020-09-11 Create motor mound connecter_1.sldprt
    [motor mound connecter_1.sldprt]
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2020-09-11 Create Rear Axle Assembly full.cfg
    [Rear Axle Assembly full.cfg]
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2020-09-11 Create Rear Axle Assembly full.sldasm
    [Rear Axle Assembly full.sldasm]
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2020-09-11 Create right side front axle.cfg
    [right side front axle.cfg]
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2020-09-11 Create Rod End Male.cfg
    [Rod End Male.cfg]
2020-09-11 Create Roll Bar Bottom Strut.sldprt
    [Roll Bar Bottom Strut.sldprt]
2020-09-11 Create Roll Bar Bottom Strut_1.sldprt
    [Roll Bar Bottom Strut_1.sldprt]
2020-09-11 Create Roll Bar Support2.sldprt
    [Roll Bar Support2.sldprt]
2020-09-11 Create Roll Bar Support2_1.sldprt
    [Roll Bar Support2_1.sldprt]
2020-09-11 Create Roll Bar Support2_mir1.sldprt
    [Roll Bar Support2_mir1.sldprt]
2020-09-11 Create Roll Bar Support2_mir1_1.sldprt
    [Roll Bar Support2_mir1_1.sldprt]
2020-09-11 Create Roll Bar Top Strut.sldprt
    [Roll Bar Top Strut.sldprt]
2020-09-11 Create Roll Bar Top Strut_1.sldprt
    [Roll Bar Top Strut_1.sldprt]
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2020-09-11 Create side plate with electronics.cfg
    [side plate with electronics.cfg]
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2020-09-11 Create side plate with electronics.sldasm
    [side plate with electronics.sldasm]
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2020-09-11 Create Side Rear Vertical Tube.sldprt
    [Side Rear Vertical Tube.sldprt]
2020-09-11 Create Side Rear Vertical Tube_1.sldprt
    [Side Rear Vertical Tube_1.sldprt]
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2020-09-11 Create Side Vertical Tube.sldprt
    [Side Vertical Tube.sldprt]
2020-09-11 Create Side Vertical Tube_1.sldprt
    [Side Vertical Tube_1.sldprt]
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2020-09-11 Create steering collum 2.sldprt
    [steering collum 2.sldprt]
2020-09-11 Create steering collum 2_1.sldprt
    [steering collum 2_1.sldprt]
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2020-09-11 Create steering mound 2.sldprt
    [steering mound 2.sldprt]
2020-09-11 Create steering mound 2_1.sldprt
    [steering mound 2_1.sldprt]
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2020-09-11 Create Upper Rear Tube.sldprt
    [Upper Rear Tube.sldprt]
2020-09-11 Create Upper Rear Tube_1.sldprt
    [Upper Rear Tube_1.sldprt]
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2020-09-11 Create Upper Side Tube.sldprt
    [Upper Side Tube.sldprt]
2020-09-11 Create Upper Side Tube_1.sldprt
    [Upper Side Tube_1.sldprt]
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2020-09-11 Create Z13 Steering Connecting Rod (short).par
2020-09-11 Create Z13 Steering Connecting Rod (short).sev
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2020-09-11 Create Z18 - brake lever tightener.par
2020-09-11 Create Z18 - brake lever tightener.sev
2020-09-11 Create Z18 - brake lever tightener.sldprt
    [Z18 - brake lever tightener.sldprt]
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2020-09-12 Created documentation folder and moved Standard GP CAD files
    Moved GP standard CAD into mechanical folder and made a documentation folder for admin, race regulations etc.
    [Battery with terminals.cfg, Battery with terminals.sldasm, Body Assembly 2.cfg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]
2020-09-12 Fixing Errors
    Fixed naming of a lot of parts, updates to rear axle mounting plate and rollhoop assembly
    [Battery with terminals.cfg, Battery with terminals.sldasm, Body Assembly 2.cfg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]
2020-09-12 Some more naming fixes and adding drivetrain parts
    [Assembly.SLDASM, Assembly.cfg, Assieme12.SLDASM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]
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2020-09-12 Revert "Merge branch 'master' of https://github.com/dire-ni/RogueGP"
    This reverts commit ea2cfeb6e111d3582672c09f0dd19b324054265f, reversing
    changes made to c1c9660045e62c40ab54b12b424c2a545f03245d.
    [Assembly.SLDASM, Assembly.cfg, Assieme12.SLDASM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]
2020-09-12 Revert "Revert "Merge branch 'master' of https://github.com/dire-ni/RogueGP""
    This reverts commit 68bef60a7df7f7228abd6a137022fe2d37a32ebe.
    [Assembly.SLDASM, Assembly.cfg, Assieme12.SLDASM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]
2020-09-12 Revert "Motor and Heatsink Added"
    This reverts commit c1c9660045e62c40ab54b12b424c2a545f03245d.
2020-09-12 Fixing another mess
    [Assembly.SLDASM, Assembly.cfg, Assieme12.SLDASM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]
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2020-09-12 Fixed motor and heatsink assembly
    [2020-motor-&-heat-sink.cfg]
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2020-09-12 Edited rolling shell & added steering column assembly
    [Rolling-Shell.cfg, steering-column.cfg]
2020-09-13 Tidied files up a bit, added more to rolling shell assembly
    [Assembly.SLDASM, Assembly.cfg, Assieme12.SLDASM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]
2020-09-13 Rolling shell assembly, RH rear axle first draft & mount plates (likely) final version
    [LH-axle-mounting-plate.cfg, MB1000.cfg, RH-axle-mounting-plate.cfg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]
2020-09-16 Update to Strut knuckles
    Fixed counterbore in strut knuckles.
    Counterbore: 14mm to fit square drive socket was 10mm
    Part lengthened: 55mm was 45mm
    Min 2mm wall thickness surrounding c'bore to avoid thin wall.
2020-09-16 Added smaller roll hoop and motor mounting plate
    [R720x100-roll-hoop.cfg, motor-mount-plate.psm]
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2020-09-17 Added rear axlie mount flattend sheet metal part
    [rear-axle mount-flat.psm]
2020-09-17 Update to motor mounting plate and rolling shell
    [MB1000.cfg, R720x100-Rolling-Shell.cfg, motor-mount-plate.psm]
2020-09-17 Rear axle mount flattened sheet
    Model updated to 2mm thickness.
    Drawing created for DFX document.
    [rear-axle mount-flat.psm]
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2020-09-22 Adding drawings and exports to documentation and fixed part view orientatons on opening
    [2020-heat-sink.stp, LH-axle.stp, RH-axle.stp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]
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2020-09-23 Corrected mistakes and changes from weekend
    Changed back hoop too 250
    changed struts too correct fit (needs checked)
    changed seat to correct size from the change too the back hoop
    [MB1000.cfg, seat-back.psm]
2020-09-23 Changes made that needed to be fixed
    Inserted small spacer for the front
    Fixed front staering so is proper ride hight
    [LH-Upright-Assembly.cfg, MB1000.cfg, RH-Upright-Assembly.cfg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]
2020-09-25 Fixes to ride hieght
    changed the holes on the back axel mounting plate
    added my design for the stearing mount
    [Front Mount braket .psm, MB1000.cfg, Rolling-Shell.cfg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]
2020-09-25 slight fixes
    motor placement
    [MB1000.cfg, Rolling-Shell.cfg]
2020-09-29 Fixed fairing position
    Moved the fairing to it's correct mounting position
    [Rolling-Shell.cfg]
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2020-10-27 Update Rear Axles
    Parts, drawings and PDF's updated to remove/shorten 12mm diameter hole
2021-08-17 Created new rear bearing design
    Creation of an axial and radial load handling bearing design to solve the split shaft problems discovered during assembly
    [20204-tvp.cfg, SKF_81104 TN.cfg, bearing-full-assembly.cfg]
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
